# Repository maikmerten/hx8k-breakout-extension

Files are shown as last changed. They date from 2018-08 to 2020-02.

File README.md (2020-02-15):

# hx8k-breakout-extension
A PCB with SRAM, buttons, LEDs and some pmod-compatible connectors for the Lattice HX8K Breakout Board

**Please notice**: This PCB only carries SRAM with a data bus width of 8 bits. This is pretty narrow and can be performance-limiting. Also, let's be honest, this PCB layout is somewhat wacky. Perhaps you might consider building [a more recent design with 16-bit SRAM](https://github.com/maikmerten/hx8k-sram16-extension) instead.

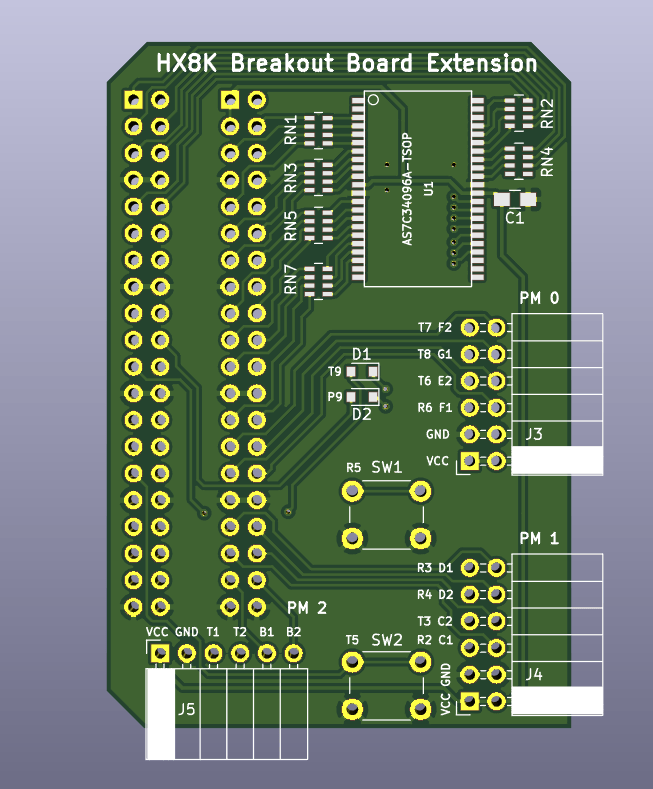
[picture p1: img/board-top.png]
top side of the board top side


## BOM

| Component | Description | Qty. |
|---|---|---|
| U1 | 4 MBit SRAM chip, 512Kx8, AS7C34096A, 10ns recommended, TSOP-II 44 | 1 |
| RN1, RN2, RN3, RN4, RN5, RN6, RN7, RN8 | 33 Ohm resistor network, 4 resistors in one package, 1206 (4x0603) package | 8 |
| C1 | 100nF ceramic capacitor, 0805 package | 1 |
| D1, D2 | SMD LEDs, red, 0805 package | 2 |
| R1, R2 | resistors for the LEDs, 330 Ohm, 0805 package | 2 |
| SW1, SW2 | 6x6 mm push buttons, THT | 2 |
| R3, R3 | optional pull-ups for SW1 and SW2, anything between 10K and 50K should be fine, 0805 package | 2 |
| J1, J2 | 2x20 male pin headers, 2.54 mm pin spacing | 2 |
| J3, J4 | 2x6 right-angled headers | 2 |
| J5 | 1x6 right-angled header | 1 |

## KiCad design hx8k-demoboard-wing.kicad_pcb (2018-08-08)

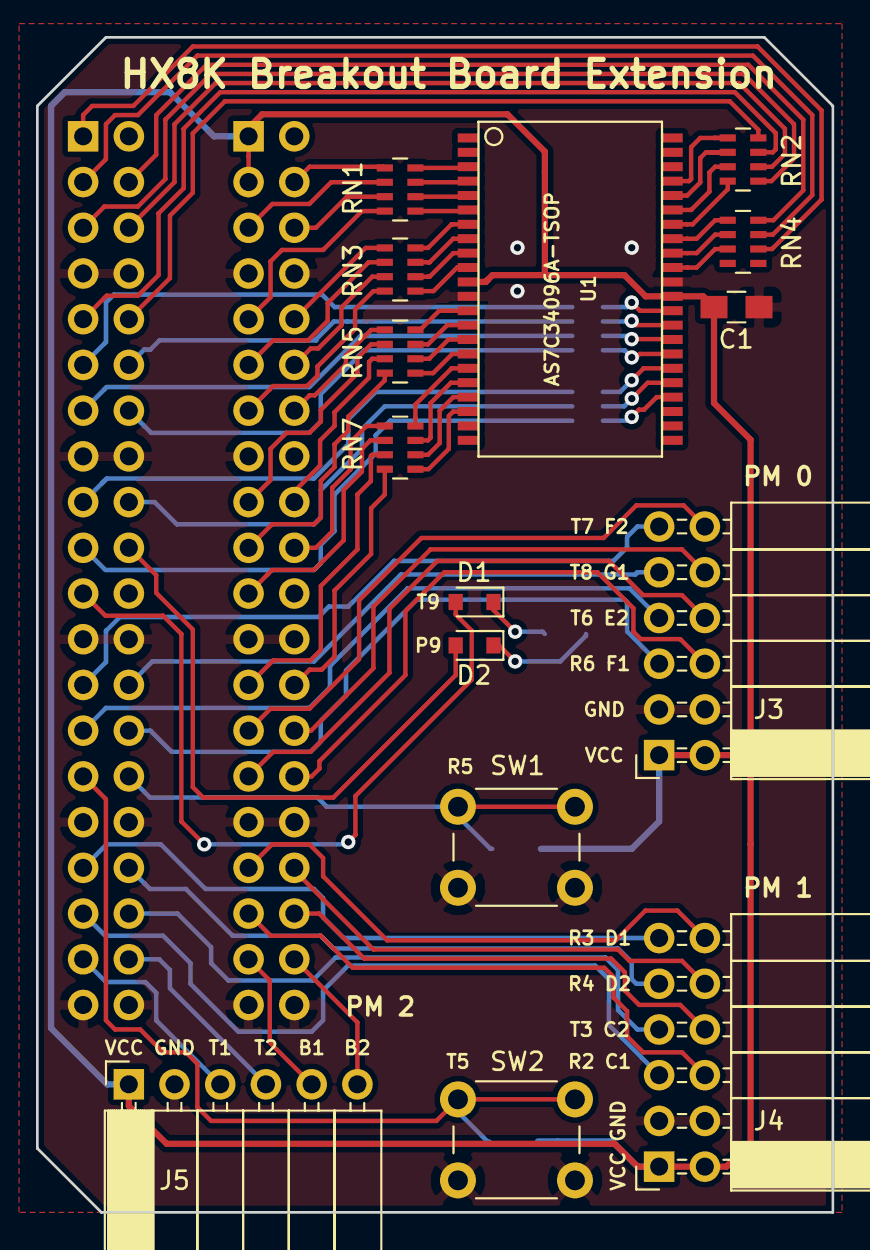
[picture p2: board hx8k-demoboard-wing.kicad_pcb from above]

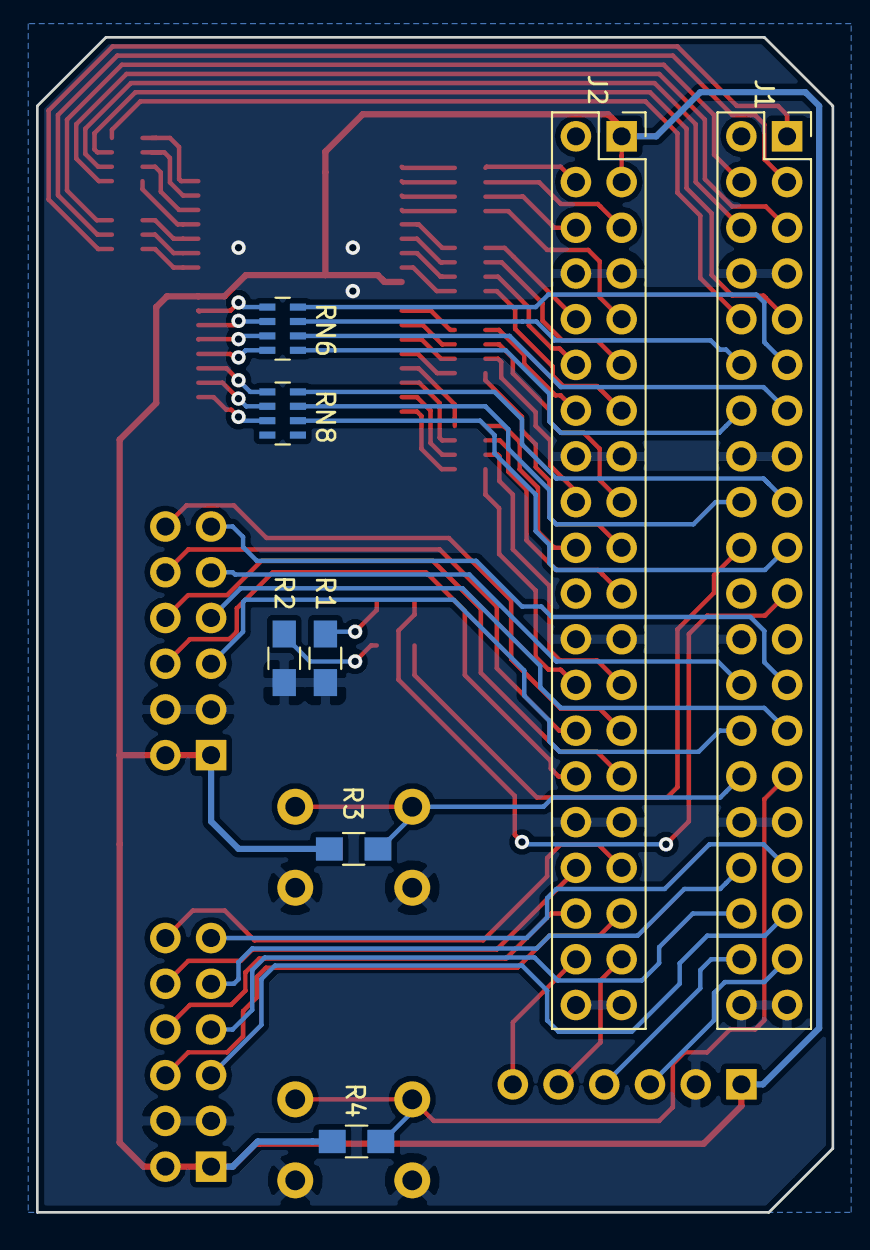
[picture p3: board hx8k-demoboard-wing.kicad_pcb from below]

Board: 2 copper layers, 44.2 x 65.3 mm, 23 parts (8 on the bottom side), 88 nets.

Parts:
C1: 100nF; C_0805_HandSoldering
D1, D2: LED; D_0805
J1, J2: Conn_02x20_Odd_Even; Socket_Strip_Straight_2x20_Pitch2.54mm
J3, J4: Conn_02x06_Odd_Even; Socket_Strip_Angled_2x06_Pitch2.54mm
J5: Conn_01x06; Socket_Strip_Angled_1x06_Pitch2.54mm
R1, R2: 300; R_0805_HandSoldering
R3, R4: 10k; R_0805_HandSoldering
RN1, RN2, RN3, RN4, RN5, RN6, RN7, RN8: R_Pack04; R_Array_Concave_4x0603
SW1, SW2: SW_Push; SW_PUSH_6mm
U1: AS7C34096A-TSOP; tsop2-44

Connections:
AD0: RN1.8, U1.3
AD1: RN1.7, U1.4
AD2: RN1.6, U1.5
AD3: RN1.5, U1.6
AD4: RN3.8, U1.7
AD5: RN5.5, U1.16
AD6: RN7.8, U1.17
AD7: RN7.7, U1.18
AD8: RN7.6, U1.19
AD9: RN7.5, U1.20
AD10: RN8.3, U1.26
AD11: RN8.2, U1.27
AD12: RN8.1, U1.28
AD13: RN6.4, U1.29
AD14: RN6.3, U1.30
AD15: RN2.4, U1.38
AD16: RN2.3, U1.39
AD17: RN2.2, U1.40
AD18: RN2.1, U1.41
B1: J2.37, J5.5
B2: J2.38, J5.6
C1: J2.35, J4.6
C2: J2.36, J4.8
CE: RN3.7, U1.8
D1: J2.33, J4.12
D2: J2.34, J4.10
E2: J2.29, J3.8
F1: J2.30, J3.6
F2: J2.27, J3.12
G1: J2.28, J3.10
G2: J2.25, RN7.3
GND: C1.2, J1.7, J1.8, J1.15, J1.16, J1.23, J1.24, J1.31, J1.32, J1.39, J1.40, J2.7, J2.8, J2.15, J2.16, J2.23, J2.24, J2.31, J2.32, J2.39, J2.40, J3.3, J3.4, J4.3, J4.4, J5.2, R1.2, R2.2, SW1.2, SW2.2, U1.12, U1.34
H1: J2.26, RN7.4
H2: J2.21, RN7.2
IO0: RN3.6, U1.9
IO1: RN3.5, U1.10
IO2: RN5.8, U1.13
IO3: RN5.7, U1.14
IO4: RN6.2, U1.31
IO5: RN6.1, U1.32
IO6: RN4.3, U1.35
IO7: RN4.2, U1.36
J1: J2.20, RN7.1
J2: J2.19, RN5.4
K1: J2.18, RN5.3
K3: J2.17, RN5.2
L1: J2.14, RN5.1
L3: J2.13, RN3.4
M1: J2.12, RN3.3
M2: J2.11, RN3.2
M11: J1.12, RN6.7
N2: J2.10, RN3.1
N3: J2.9, RN1.4
N10: J1.11, RN6.8
N12: J1.9, RN2.7
unnamed: D1.1, R1.1
unnamed: D2.1, R2.1
OE: RN4.1, U1.37
P1: J2.5, RN1.2
P2: J2.6, RN1.3
P8: J1.19, RN8.6
P9: D2.2, J1.20
P10: J1.14, RN6.5
P13: J1.10, RN2.8
R1: J2.4, RN1.1
R2: J1.35, J4.5
R3: J1.33, J4.11
R4: J1.34, J4.9
R5: J1.30, R3.1, SW1.1
R6: J1.28, J3.5
R10: J1.18, RN8.7
R16: J1.1, RN4.6
T1: J1.37, J5.3
T2: J1.38, J5.4
T3: J1.36, J4.7
T5: J1.29, R4.1, SW2.1
T6: J1.27, J3.7
T7: J1.25, J3.11
T8: J1.26, J3.9
T9: D1.2, J1.21
T10: J1.17, RN8.8
T11: J1.13, RN6.6
T13: J1.5, RN2.5
T14: J1.6, RN2.6
T15: J1.3, RN4.7
T16: J1.4, RN4.8
VCC33: C1.1, J2.1, J2.3, J3.1, J3.2, J4.1, J4.2, J5.1, R3.2, R4.2, U1.11, U1.33
WE: RN5.6, U1.15

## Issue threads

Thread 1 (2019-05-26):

Available boards?

janrinze, 2019-05-26:
I was wondering if there are assembled boards available.
Nice board, would love to run some tests on it.

maikmerten, 2019-05-26:
I think I still have one unpopulated PCB somewhere and necessary parts, so I can part with one assembled board for cost of shipping. I don't plan to make assembled boards generally available, but looking at your github repos, it seems you're interested in open-source FPGA designs, so I'll happily support that. Just be aware that the board comes with no warranty whatsoever and that my soldering is not up to factory standards ;-)

Feel free to contact me at maikmerten (at) googlemail (dot) com.

janrinze, 2019-05-28:
email sent.
looking forward to test it :-)

maikmerten, 2019-05-28:
Email received, will close the issue here.

Closed 2019-05-28.

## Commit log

2018-08-08 commit project files
    [hx8k-demoboard-wing.kicad_pcb, hx8k-demoboard-wing.sch]
2018-08-08 add an image of the board
2018-08-08 commit gerber files
2018-08-25 add BOM to README
